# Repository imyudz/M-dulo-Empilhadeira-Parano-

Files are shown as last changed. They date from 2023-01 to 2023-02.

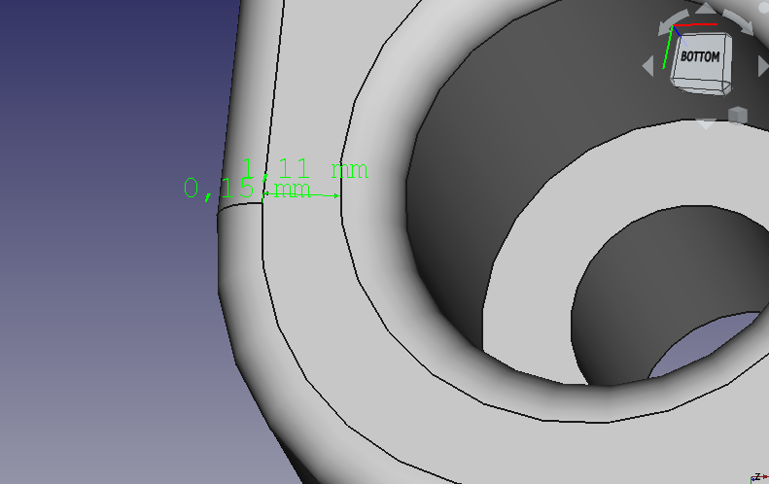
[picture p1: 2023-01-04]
Físico/CASE/VS1/cotas escariado tampa.png

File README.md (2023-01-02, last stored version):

# Módulo Empilhadeira Paranoá -- IIOT, Indústria 4.0

Desenvolvido por mim, para automatizar os chamados de empilhadeira da empresa Paranoa em conjunto com a DataWake
O projeto consiste na utilização de:
- ESP8266 ou ESP32
- Modelagem 3D para comportar a placa utilizada
- Comunicação do ESP com Software Supervisório ELIPSE E3 via MQTT

Todas as etapas desenvolvidas durante o ano de 2022 por mim.

OBJETIVO: A máquina, quando identificada através de sensores que precisa abastecer algum material, já realiza um chamado para o dispositivo que está fixado na empilhadeira

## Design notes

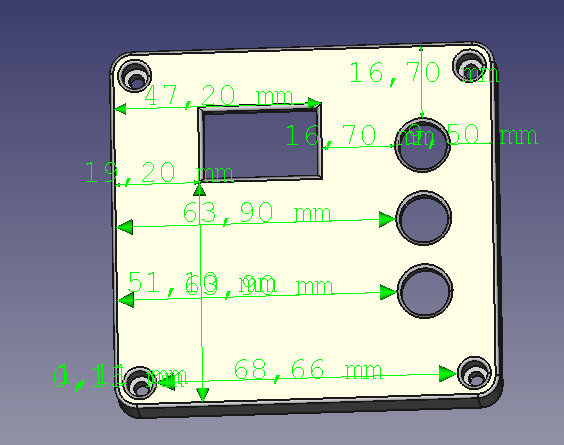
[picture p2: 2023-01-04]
Físico/CASE/VS1/cotas tampa interia.png

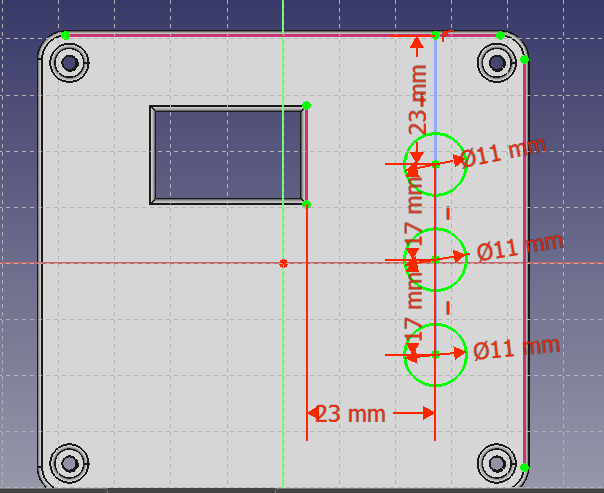
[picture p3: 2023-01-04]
Físico/CASE/VS1/cotas 1 - botões.png

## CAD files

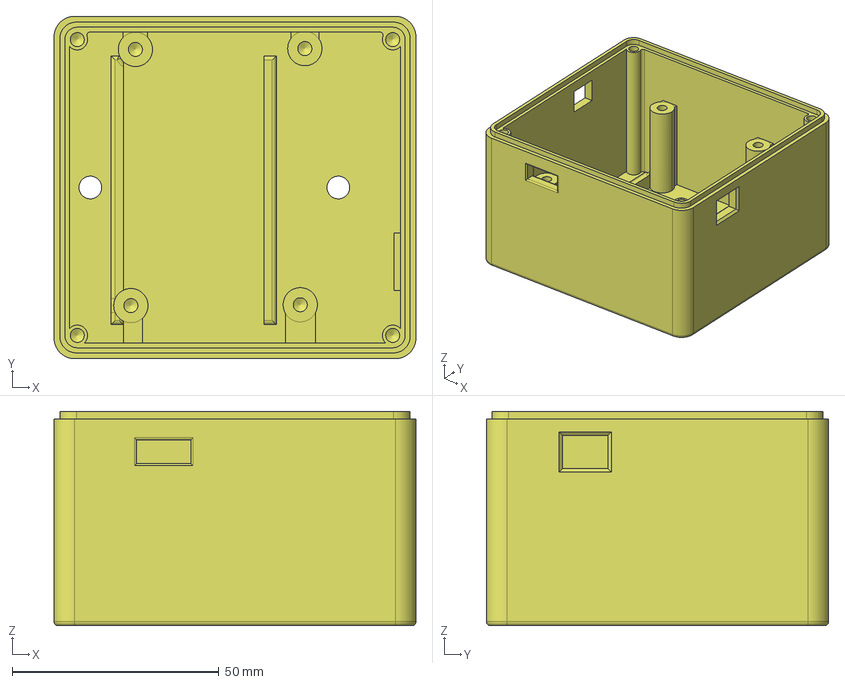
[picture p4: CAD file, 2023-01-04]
Físico/CASE/VS1/CASE DEFINITIVO - BACKUP.FCStd
87.6 x 82.8 x 51.9 mm

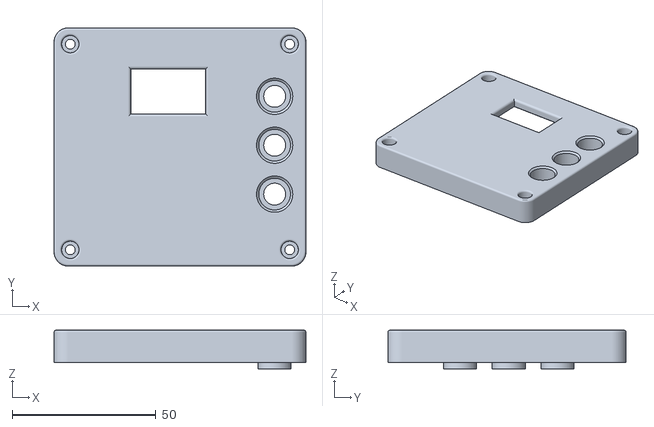
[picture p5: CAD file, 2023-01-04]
Físico/CASE/VS1/IMPRESSÃO vs1/CASE DEFINITIVO-TAMPA.stl
87.6 x 82.8 x 13.5

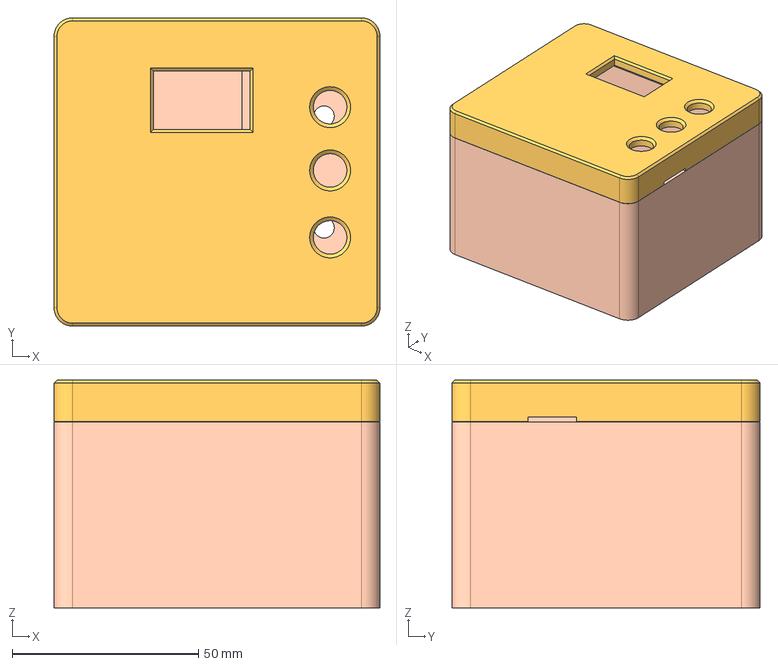
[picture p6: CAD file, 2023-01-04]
Físico/CASE/VS2/CASE DEFINITIVO MUTÁVEL VS 2.FCStd
87.6 x 82.8 x 61.2 mm
CASE_NO_BREAKABLE
TAMPA

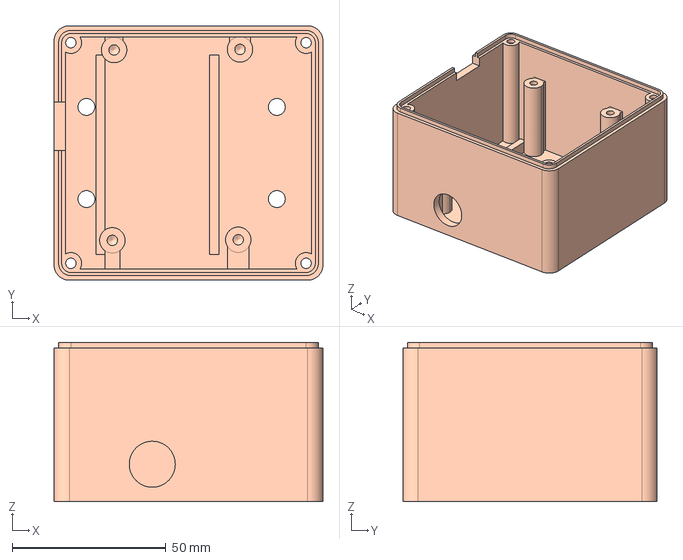
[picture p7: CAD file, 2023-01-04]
Físico/CASE/VS3.1/CASE DEFINITIVO MUTÁVEL VS 3.1.FCStd
87.6 x 82.8 x 51.9 mm

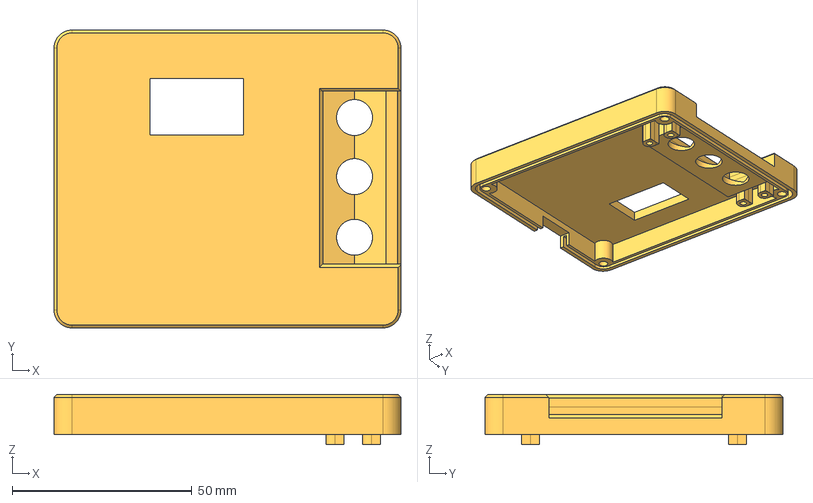
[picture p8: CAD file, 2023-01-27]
Físico/CASE/VS4/CASE DEFINITIVO MUTÁVEL VS 4.FCStd
96.5 x 82.8 x 14.0 mm

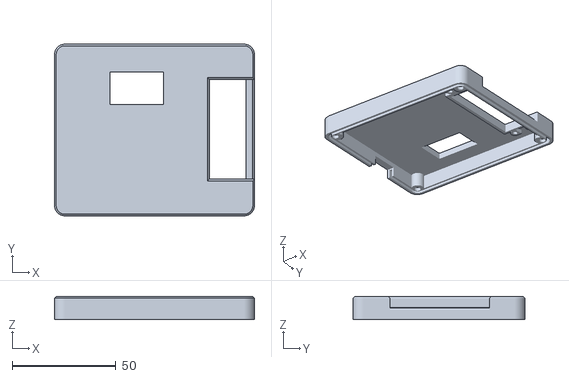
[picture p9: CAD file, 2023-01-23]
Físico/CASE/VS4/Impressão/CASE DEFINITIVO MUTÁVEL VS 4-TAMPA.stl
96.5 x 82.8 x 11.2

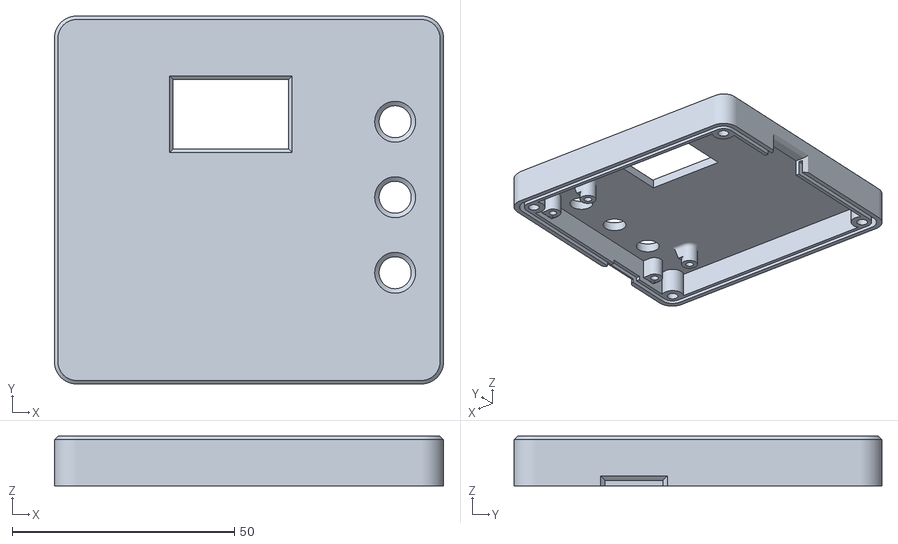
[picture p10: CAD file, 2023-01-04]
Físico/CASE/VS2/IMPRESSÃO vs2/CASE DEFINITIVO MUTÁVEL VS 2-TAMPA.stl
87.6 x 82.8 x 11.2

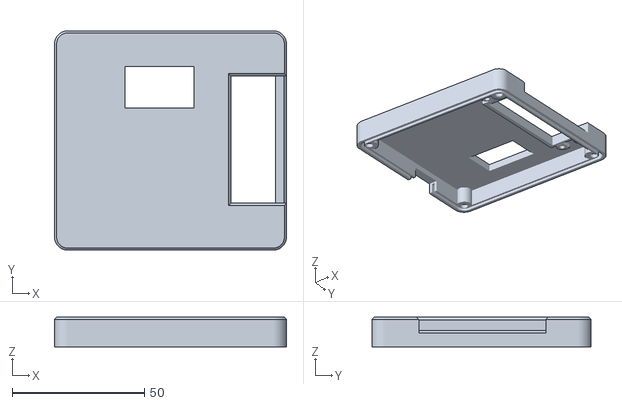
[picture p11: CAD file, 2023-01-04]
Físico/CASE/VS3.1/IMPRESSAO 3.1/TAMPA_3.1.stl
87.6 x 82.8 x 11.2

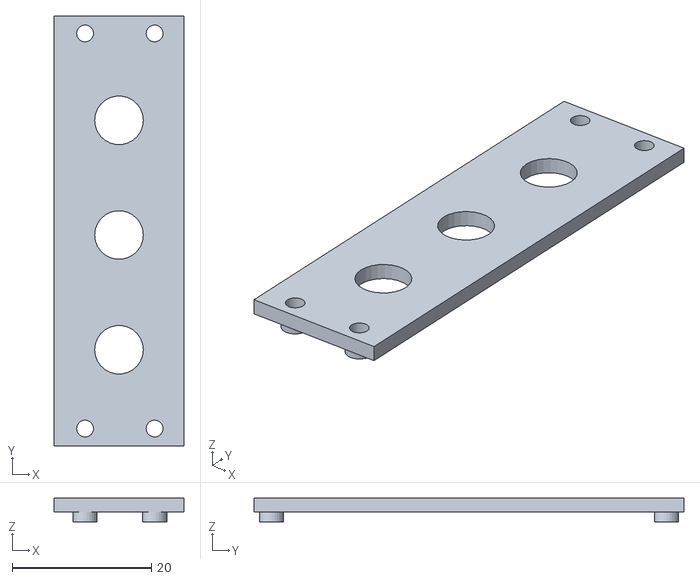
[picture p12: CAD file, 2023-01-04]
Físico/CASE/VS3.1/IMPRESSAO 3.1/BOTOES_3.1.stl
18.7 x 61.8 x 3.40

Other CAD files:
Físico/CASE/VS3.1/IMPRESSAO 3.1/CASE 3.1.stl
Físico/CASE/VS3/CASE DEFINITIVO MUTÁVEL VS 3.FCStd
Físico/CASE/VS1/IMPRESSÃO vs1/CASE DEFINITIVO-CASE.stl
Físico/CASE/VS2/IMPRESSÃO vs2/CASE DEFINITIVO MUTÁVEL VS 2-tampa vs2.stl

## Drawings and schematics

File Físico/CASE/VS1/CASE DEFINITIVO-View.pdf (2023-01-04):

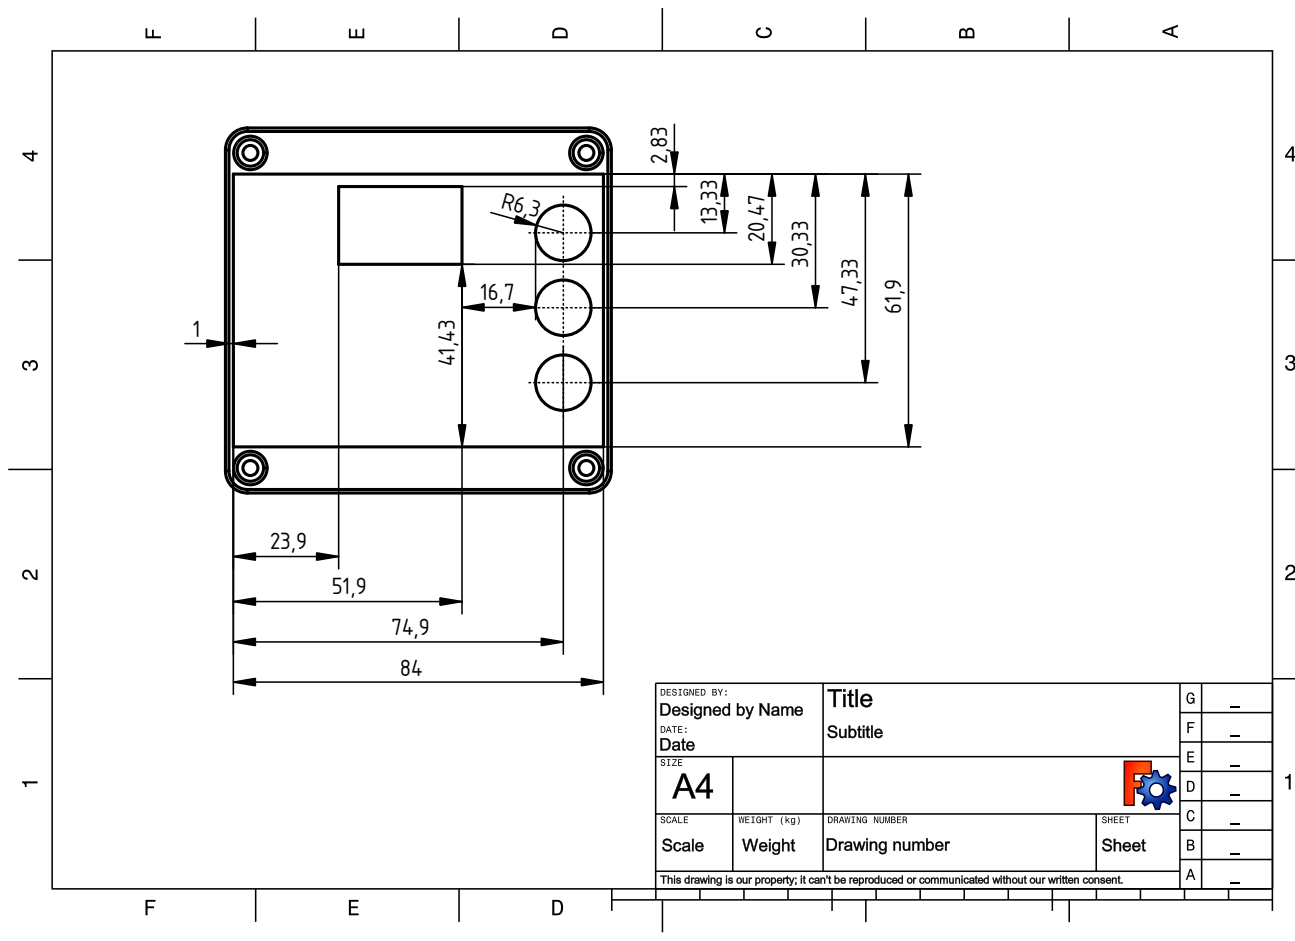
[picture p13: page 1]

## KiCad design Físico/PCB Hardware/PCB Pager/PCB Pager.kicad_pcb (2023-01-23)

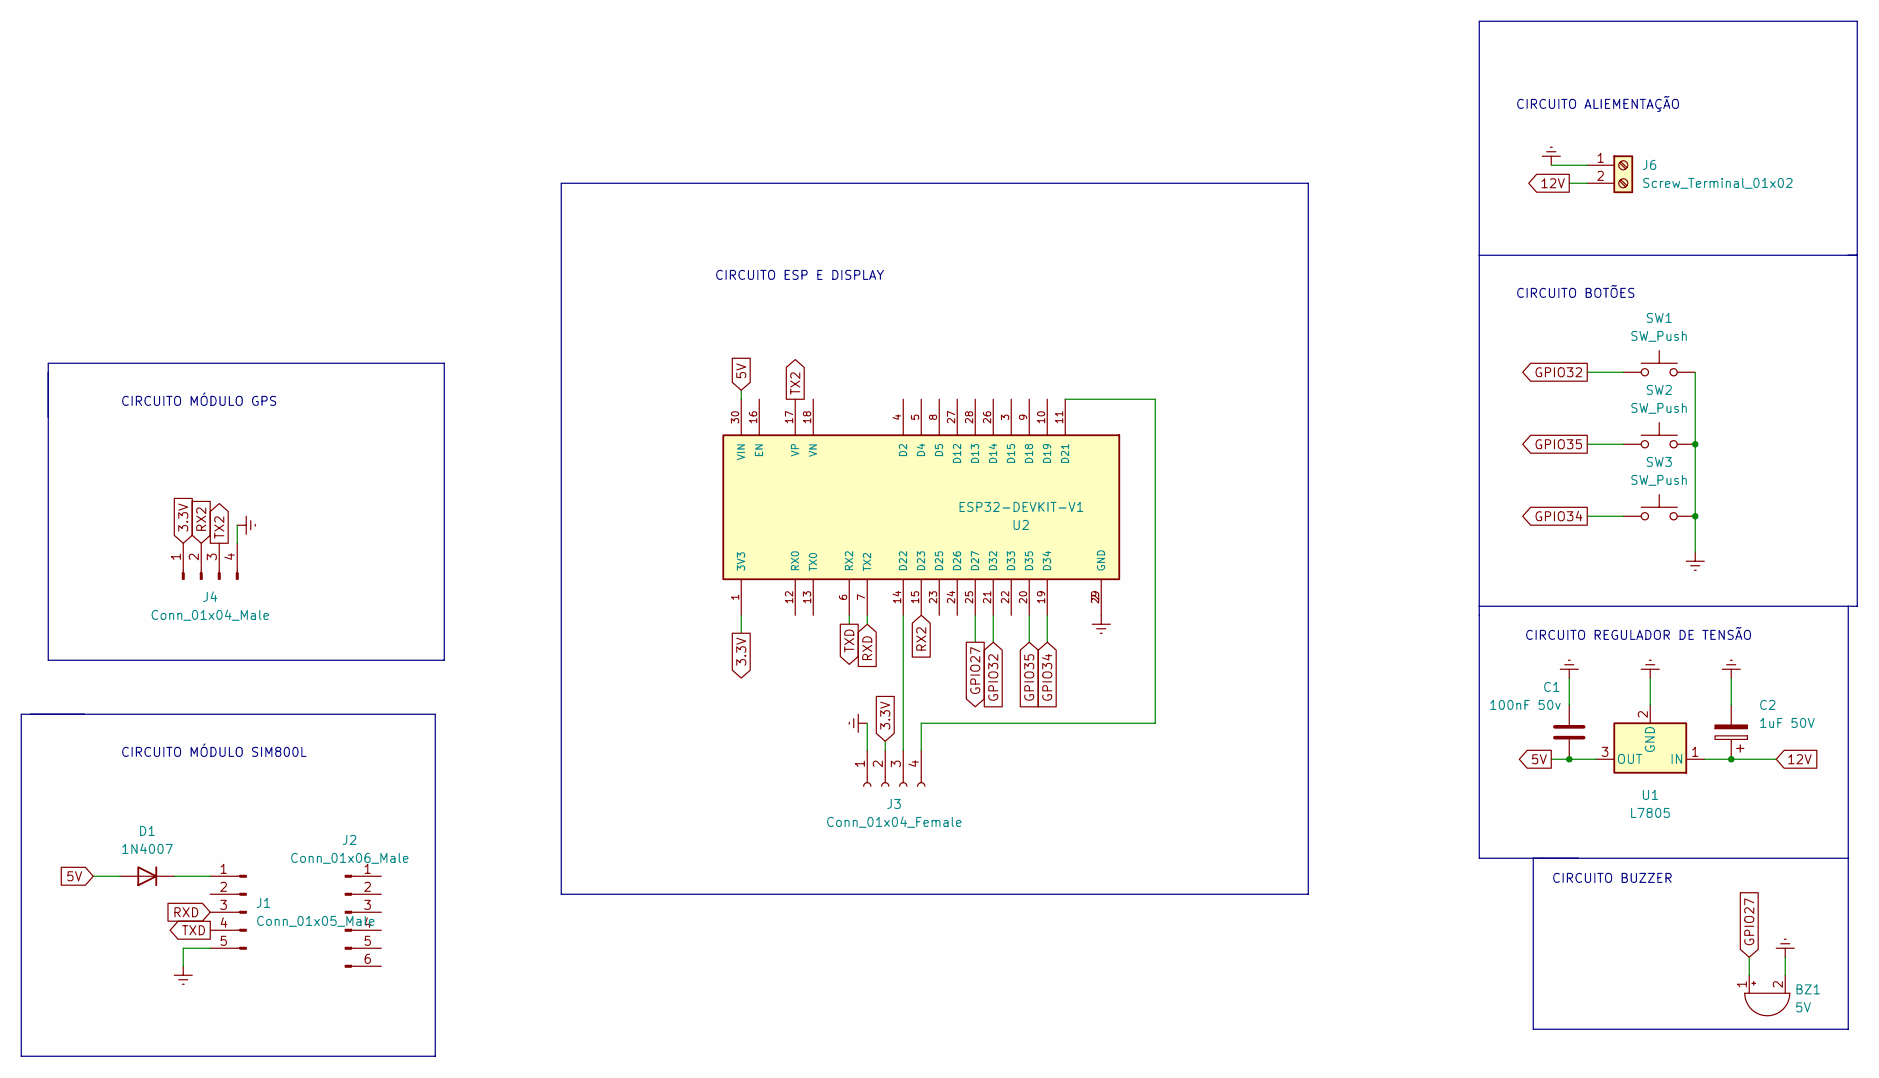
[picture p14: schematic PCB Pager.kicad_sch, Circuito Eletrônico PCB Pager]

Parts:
BZ1: 5V; Buzzer_12x9.5RM7.6
C1: 100nF 50v; C_Disc_D7.5mm_W4.4mm_P5.00mm
C2: 1uF 50V; CP_Radial_D5.0mm_P2.50mm
D1: 1N4007; D_DO-41_SOD81_P10.16mm_Horizontal
J1: Conn_01x05_Male; PinHeader_1x05_P2.54mm_Vertical
J2: Conn_01x06_Male; PinHeader_1x06_P2.54mm_Vertical
J3: Conn_01x04_Female; PinSocket_1x04_P2.54mm_Vertical
J4: Conn_01x04_Male; PinHeader_1x04_P2.54mm_Vertical
J6: Screw_Terminal_01x02; TerminalBlock_bornier-2_P5.08mm
SW1, SW2, SW3: SW_Push; SW_PUSH-12mm
U1: L7805; TO-220-3_Horizontal_TabDown
U2: ESP32-DEVKIT-V1; MODULE_ESP32_DEVKIT_V1; PARTREV N/A

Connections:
3.3V: J3.2, J4.1, U2.1 (3V3)
5V: C1.1, D1.2 (A), U1.3 (OUT), U2.30 (VIN)
12V: C2.1, J6.2, U1.1 (IN)
Earth: BZ1.2 (+), C1.2, C2.2, J1.5, J3.1, J4.4, J6.1, SW1.2, SW2.2, SW3.2, U1.2 (GND), U2.2 (GND), U2.29 (GND)
GPIO27: BZ1.1 (-), U2.25 (D27)
GPIO32: SW1.1, U2.21 (D32)
GPIO34: SW3.1, U2.19 (D34)
GPIO35: SW2.1, U2.20 (D35)
unnamed: D1.1 (K), J1.1
unnamed: J3.3, U2.14 (D22)
unnamed: J3.4, U2.11 (D21)
RX2: J4.2, U2.15 (D23)
RXD: J1.3, U2.7 (TX2)
TX2: J4.3, U2.17 (VP)
TXD: J1.4, U2.6 (RX2)

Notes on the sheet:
CIRCUITO BOTÕES
CIRCUITO BUZZER
CIRCUITO MÓDULO GPS
CIRCUITO ALIEMENTAÇÃO
CIRCUITO ESP E DISPLAY
CIRCUITO REGULADOR DE TENSÃO
CIRCUITO MÓDULO SIM800L

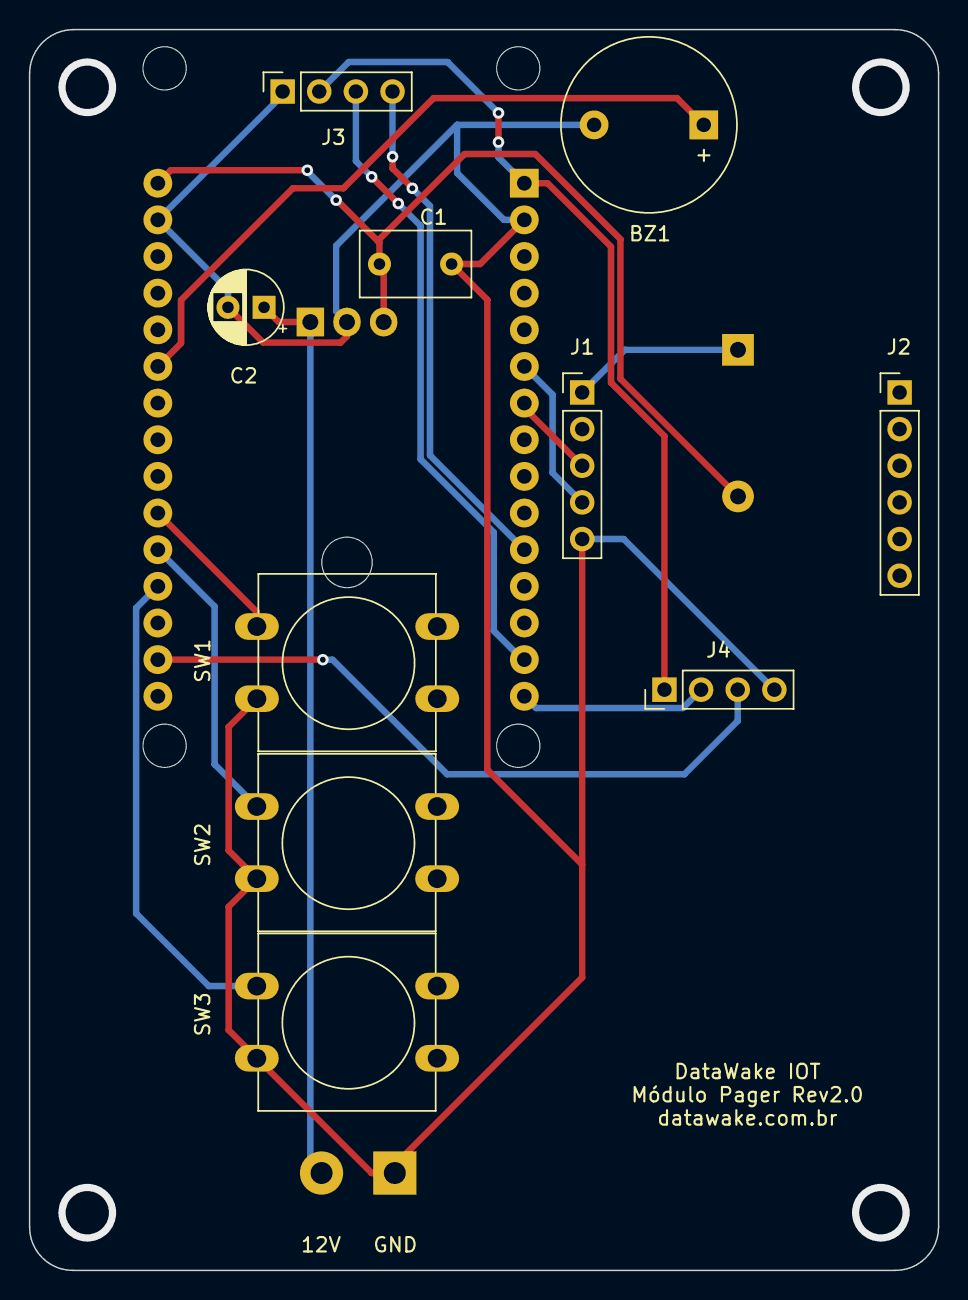
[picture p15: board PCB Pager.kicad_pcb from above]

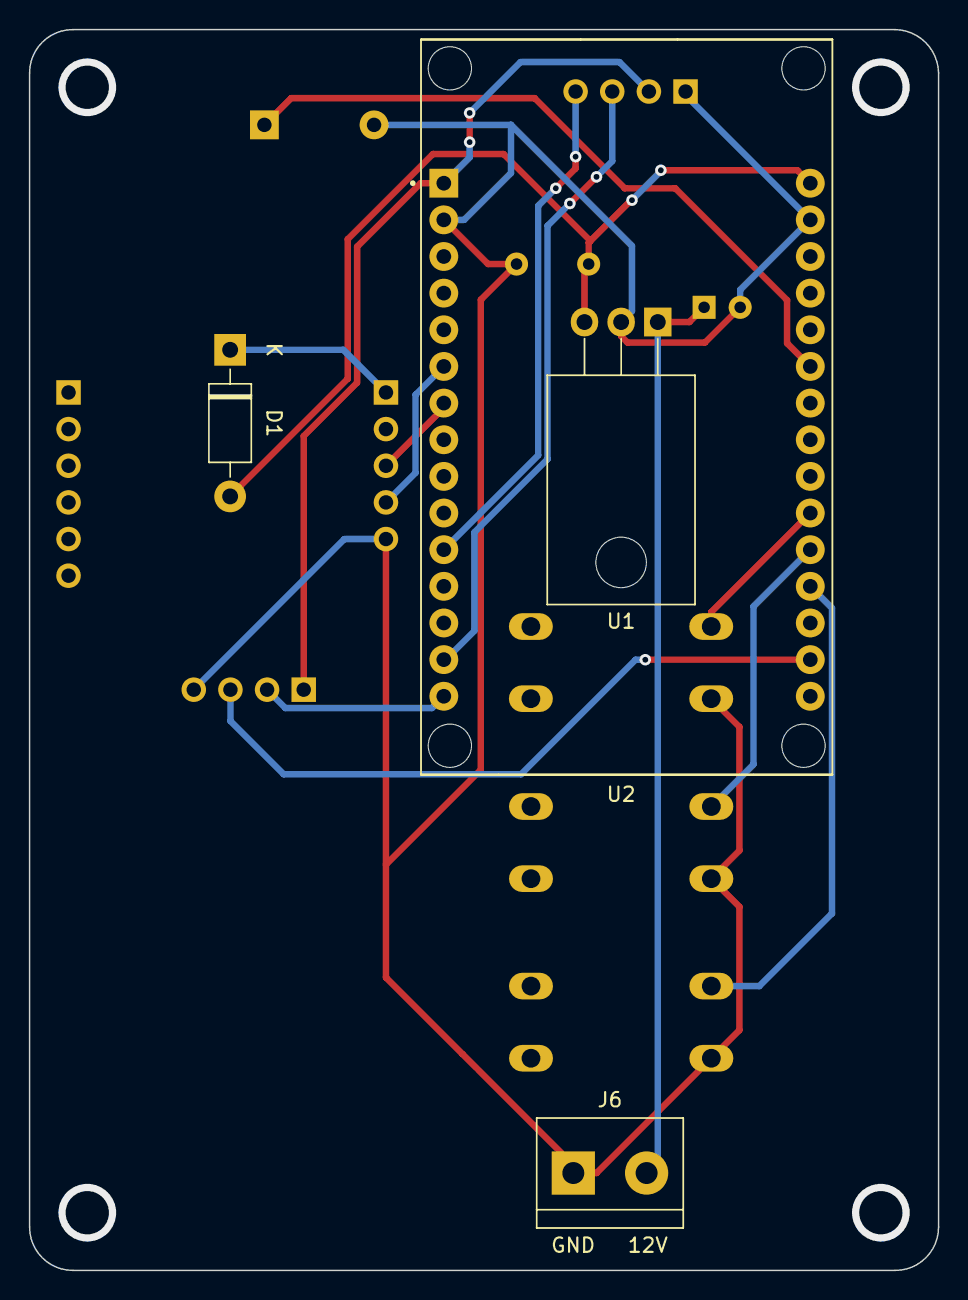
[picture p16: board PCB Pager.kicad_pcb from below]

Board: 2 copper layers, 63.0 x 86.0 mm, 14 parts (4 on the bottom side), 15 nets.

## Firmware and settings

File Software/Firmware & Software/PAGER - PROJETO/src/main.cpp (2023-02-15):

/*
  PREDEFINIÇÕES PARA OS STATUS DO PAGER
    0-LAST WILL
    1-RECEBIDO
    2-ACEITO
    3-CANCELADO
    4-PARADO
    5-FINALIZADO
    6-DESCONECTADO COM OPERAÇÃO EM ANDAMENTO
    7-PARADA FINALIZADA
*/

////////////////////////////////////////////////////////////////////////////////////////////////////////////

/////////////////////////////////////////////////////////////////////////////////////////////////////////////
//                                            BIBLIOTECAS
/////////////////////////////////////////////////////////////////////////////////////////////////////////////
#include        <Arduino.h>          //padrões arduino
#include        <Wire.h>             //Display
#include        "SSD1306.h"          //Display
#include        <PubSubClient.h>     //MQTT
#include        <WiFiClient.h>       //MQTT
#include        <ESP8266WiFi.h>      //WiFi
#include        <Preferences.h>      //EEPROM
#include        <neotimer.h>         //Substituição do Millis

/////////////////////////////////////////////////////////////////////////////////////////////////////////////
//                                            CÓDIGO DE PARADAS                                            //
////////////////////////////////////////////////////////////////////////////////////////////////////////////
String    MANUT_MEC       =    "2";
String    MANUT_EL        =    "1";
String    BANHEIRO        =    "7";
String    REFEICAO        =    "9";
String    AUDITORIA       =    "11";
String    TREINAMENTO     =    "13";
String    TRY_OUT         =    "17";
String    FALTA_ABASTEC   =    "24";
String    MANUT_PREV      =    "25";
String    TESTES_DIV      =    "36";
String    NAO_APONTADO    =    "49";
String    TESTE_MANUT     =    "59";
String    AGUARD_EMPILH   =    "76";

String cod_parada = "";

////////////////////////////////////////////////////////////////////////////////////////////////////////////
//                                      Configuração WIFI
////////////////////////////////////////////////////////////////////////////////////////////////////////////
const char* ssid = "ParanoaSA";
const char* password = "0e6f1e0dff";
//const char* ssid = "victor";
//const char* password = "admin123";
WiFiClient wifiClient;


////////////////////////////////////////////////////////////////////////////////////////////////////////////
//                                      Configuração MQTT
////////////////////////////////////////////////////////////////////////////////////////////////////////////
//*************************SERVER:
//const char* BROKER_MQTT = "192.168.0.82"; // URL OU IP DO BROKER que se deseja utilizar -- SERVIDOR DE FUNCIONAMENTO
const char* BROKER_MQTT = "192.168.0.13"; // URL OU IP DO BROKER que se deseja utilizar -- SERVIDOR DE TESTE
//const char* BROKER_MQTT = "broker.hivemq.com"; // URL OU IP DO BROKER que se deseja utilizar -- SERVIDOR DE TESTE
int BROKER_PORT = 1883; //Porta do BROKER MQTT
#define MQTTsubQos  1   //qos of subscribe
#define MQTTpubQos  1   //qos of subscribe
//*************************CLIENT:
PubSubClient MQTT(wifiClient); //Instancia objeto MQTT que se vincula ao objeto do espClient
//****************DEFINE OS TÓPICOS DESSE PAGER
#define TOPIC_PUBLISH "PG2/STATUS"
const char* PAGER_NAME = "PG2";
String STATUS_PAGER = (String)PAGER_NAME+"/STATUS";
String UNIDADE = (String)PAGER_NAME+"/LOCAL";
String PRODUTO = (String)PAGER_NAME+"/PRODUTO";
String SOLICITACAO = (String)PAGER_NAME+"/SOLICITACAO";
String COD_PARADA = (String)PAGER_NAME+"/CODPARADA";
String ETIQ_MONTARACK = (String)PAGER_NAME+"/ETIQ_MONTARACK";


///////////////////////////////////////////////////////////////////////////////////////////////////////////
//                                     MAPEAMENTO DE HARDWARE
//////////////////////////////////////////////////////////////////////////////////////////////////////////
//definições para os botões da placa
unsigned long tempo_botao = millis();
#define btcima 2 //D4
#define btbaixo 12 //D3
#define btenter 0 //D6
#define buzzer 14
#define DEBOUNCE_BOTAO 300
#define QUANT_VEZES_BUZZER 4


///////////////////////////////////////////////////////////////////////////////////////////////////////////////
//                                   CONFIGURAÇÕES DO MENU E DISPLAY
///////////////////////////////////////////////////////////////////////////////////////////////////////////////
//Adafruit_SSD1306 display(128, 64, &Wire, -1);
SSD1306Wire display(0x3c, SDA, SCL);
//variaveis menu
byte navegacao_status = 0; //controla em qual página do MENU o dispositivo se encontra durante a navegação
byte altera_parametros = 0; //indica o parâmtro que está sendo atualizado
String sts_sistema = "";   //define o status da integridade dos dados do dispositivo. Se o valor for maior que 0, alguma informação não foi cadastrada no dispositivo e por isso não acontecerá a comunicação com o servidor MQTT
String produtoDisplay; //recebe o produto que foi atribuido


////////////////////////////////////////////////////////////////////////////////////////////////////////
//                                       Configurações EEPROM                                         //
////////////////////////////////////////////////////////////////////////////////////////////////////////
#define EEPROM_SOLICITACOES "blocoSolicitacoes"
#define EEPROM_ETIQUETA "blocoEtiqueta"
#define EEPROM_ENDERECO_SOLICITACOES "id_solicitacoes"
#define EEPROM_ENDERECO_ETIQUETA "cod_etiquetaMontaRack"
Preferences EEPROMdata;
float id_solicitacoes;

////////////////////////////////////////////////////////////////////////////////////////////////////////
//                                       Configurações NEOTIMER                                       //
///////////////////////////////////////////////////////////////////////////////////////////////////////
Neotimer tempoBuzzerLigado = Neotimer(70);
Neotimer tempoBuzzerDesligado = Neotimer(70);


///////////////////////////////////////////////////////////////////////////////////////////////////////////////
//                                           TAGS GLOBAIS                                                    //
///////////////////////////////////////////////////////////////////////////////////////////////////////////////
String status_chamada = "";
String produto = "";
String local = "";
String solicitacao = "";
String etiq_montaRack = "";
int selecionado = 0;
int navegado = -1;
int selecionadoOP = 0;
int navegadoOP = -1;
int selecionadoParada = 0;
int navegadoParada = -1;
int selecionadoFinalParada = 0;
int navegadoFinalParada = -1;
unsigned long ultimoEnvio = 0;
unsigned long ultimoEnvio1 = millis();
unsigned long ultimoEnvio2 = 0;
unsigned long ultimoEnvio3 = 0;
unsigned long ultimoEnvio4 = 0;
unsigned long ultimoEnvio5 = millis();
unsigned long ultimoEnvio6 = 0;
unsigned long ultimoEnvio7 = 0;
unsigned long ultimaChamada = 0;
unsigned long esperaRetornoReinicio = millis();
int salva_ponto;
int estado_antes_parada = 0;
int flag = 0;
boolean desconexaoPendente = false;


//////////////////////////////////////////////////////////////////////////////////////////////////////////////
//Endereços de Imagens 
/////////////////////////////////////////////////////////////////////////////////////////////////////////////
const unsigned char PROGMEM logo_dw [] = {0x00, 0x00, 0x00, 0x00, 0x00, 0x00, 0x00, 0x00, 0x00, 0x00, 0x00, 0x00, 0x00, 0x00, 0x00, 0x00, 0x00, 0x00, 0x00, 0x00, 0x00, 0x00, 0x00, 0x00, 0x00, 0x00, 0x00, 0x00, 0x00, 0x00, 0x01, 0xC0, 0x00, 0x00, 0x00, 0x00, 0x01, 0xC0, 0x00, 0x00, 0x00, 0x00, 0x00, 0x0F, 0x80, 0x03, 0x80, 0x00, 0x00, 0x0F, 0xF0, 0x03, 0x80, 0x00, 0x00, 0x0F, 0xF8, 0x07, 0xC0, 0x00, 0x00, 0x70, 0x3C, 0x07, 0xC0, 0x00, 0x00, 0x70, 0x1E, 0x06, 0xE0, 0x00, 0x00, 0x70, 0x0E, 0x0E, 0xE0, 0x00, 0x00, 0x70, 0x07, 0x0C, 0x70, 0x00, 0x00, 0x70, 0x07, 0x1C, 0x70, 0x00, 0x00, 0x70, 0x07, 0x1C, 0x38, 0x00, 0x00, 0x70, 0x07, 0x38, 0x38, 0x00, 0x00, 0x70, 0x07, 0x38, 0x38, 0x00, 0x00, 0x70, 0x0E, 0x70, 0x1C, 0x00, 0x00, 0x70, 0x1E, 0x70, 0x1C, 0x00, 0x00, 0x70, 0x7C, 0x60, 0x0E, 0x00, 0x00, 0x7F, 0xF8, 0xE0, 0x0E, 0x00, 0x00, 0x7F, 0xF0, 0xE0, 0x07, 0x00, 0x00, 0x00, 0x00, 0x00, 0x00, 0x00, 0x00, 0x00, 0x00, 0x00, 0x00, 0x00, 0x00, 0x00, 0x00, 0x00, 0x00, 0x00, 0x00, 0x30, 0x01, 0xC0, 0x07, 0x00, 0x00, 0x38, 0x01, 0xE0, 0x0E, 0x00, 0x00, 0x18, 0x03, 0xE0, 0x0E, 0x00, 0x00, 0x1C, 0x03, 0xF0, 0x0C, 0x00, 0x00, 0x1C, 0x07, 0x70, 0x1C, 0x00, 0x00, 0x0E, 0x07, 0x30, 0x18, 0x00, 0x00, 0x0E, 0x0E, 0x38, 0x38, 0x00, 0x00, 0x06, 0x0E, 0x38, 0x38, 0x00, 0x00, 0x07, 0x0C, 0x1C, 0x70, 0x00, 0x00, 0x03, 0x1C, 0x1C, 0x70, 0x00, 0x00, 0x03, 0x9C, 0x0E, 0x60, 0x00, 0x00, 0x03, 0xB8, 0x0E, 0xE0, 0x00, 0x00, 0x01, 0xF8, 0x06, 0xC0, 0x00, 0x00, 0x01, 0xF0, 0x07, 0xC0, 0x00, 0x00, 0x00, 0xF0, 0x07, 0xC0, 0x00, 0x00, 0x00, 0xE0, 0x03, 0x80, 0x00, 0x00, 0x00, 0x00, 0x00, 0x00, 0x00, 0x00, 0x00, 0x00, 0x00, 0x00, 0x00, 0x00, 0x00, 0x00, 0x00, 0x00, 0x00, 0x00, 0x00, 0x00, 0x00, 0x00, 0x00, 0x00, 0x00, 0x00, 0x00, 0x00, 0x00, 0x00, 0x00, 0x00, 0x00, 0x00, 0x00};
/*const unsigned char PROGMEM icone_config [] = {0x00, 0x00, 0x04, 0x20, 0x00, 0x00, 0x0E, 0x70, 0x00, 0x00, 0x0F, 0xF0, 0x00, 0x00, 0x0F, 0xF0, 0x00, 0x00, 0x7F, 0xFE, 0x00, 0x00, 0xFE, 0x7F, 0x00, 0x00, 0x7C, 0x3E, 0x00, 0x00, 0x38, 0x1C, 0x00, 0x00, 0x38, 0x1C, 0x00, 0x00, 0x7C, 0x3E, 0x00, 0x00, 0xFE, 0x7F, 0x00, 0x70, 0x7F, 0xFE, 0x00, 0x70, 0x0F, 0xF0, 0x00, 0x70, 0x0F, 0xF0, 0x1C, 0xF9, 0xCE, 0x70, 0x3F, 0xFF, 0xE4, 0x20, 0x1F, 0xFF, 0xC0, 0x00, 0x0F, 0xFF, 0x80, 0x00, 0x1F, 0x8F, 0x80, 0x00, 0x1F, 0x07, 0xC0, 0x00, 0xFE, 0x03, 0xF8, 0x00, 0xFE, 0x03, 0xF8, 0x00, 0xFE, 0x03, 0xF8, 0x00, 0x1E, 0x07, 0xC0, 0x00, 0x1F, 0x07, 0x80, 0x00, 0x0F, 0xFF, 0x80, 0x00, 0x1F, 0xFF, 0xC0, 0x00, 0x3F, 0xFF, 0xC0, 0x00, 0x1D, 0xFD, 0xC0, 0x00, 0x08, 0x70, 0x80, 0x00, 0x00, 0x70, 0x00, 0x00, 0x00, 0x70, 0x00, 0x00};*/
/*const unsigned char PROGMEM icone_info [] = {0x7F, 0xFF, 0xFF, 0xF0, 0xC0, 0x00, 0x00, 0x10, 0x80, 0x00, 0x00, 0x10, 0x80, 0x00, 0x00, 0x10, 0xFF, 0xFF, 0xFF, 0xF0, 0xFF, 0xFF, 0xFF, 0xF0, 0x80, 0x00, 0x00, 0x10, 0x80, 0x00, 0x00, 0x10, 0x80, 0x00, 0x00, 0x10, 0x80, 0x00, 0x00, 0x10, 0x8E, 0x7F, 0xFF, 0x10, 0x80, 0x00, 0x00, 0x10, 0x80, 0x00, 0x00, 0x10, 0x8E, 0x7F, 0xFF, 0x10, 0x80, 0x00, 0x00, 0x10, 0x80, 0x00, 0x00, 0x10, 0x8E, 0x7F, 0xFF, 0x10, 0x80, 0x00, 0x00, 0x10, 0x80, 0x00, 0x00, 0x10, 0x86, 0x7F, 0xC0, 0x10, 0x80, 0x00, 0x03, 0x00, 0x80, 0x00, 0x1F, 0xE0, 0x80, 0x00, 0x33, 0x38, 0x80, 0x00, 0xCF, 0xCC, 0x80, 0x01, 0x88, 0x46, 0xFF, 0xFB, 0x1B, 0x63, 0x00, 0x03, 0x1B, 0x23, 0x00, 0x01, 0x98, 0x66, 0x00, 0x00, 0xCC, 0xCC, 0x00, 0x00, 0x67, 0x98, 0x00, 0x00, 0x3C, 0xF0, 0x00, 0x00, 0x0F, 0xC0};*/


//////////////////////////////////////////////////////////////////////////////////////////////////////////////
//                                         Códigos das Funções                                              //
/////////////////////////////////////////////////////////////////////////////////////////////////////////////
void (*funcReset)() = 0;

void apitaBuzzer(){
  for (int i = 0; i < QUANT_VEZES_BUZZER; i++)
  {
    //LÓGICA EM TESTE:
    /*  tempoBuzzerLigado.start();
      if(tempoBuzzerLigado.waiting()) digitalWrite(buzzer, HIGH);
      if(tempoBuzzerLigado.done()){ digitalWrite(buzzer, LOW); tempoBuzzerDesligado.start();}
      if(tempoBuzzerDesligado.waiting()) digitalWrite(buzzer, LOW);
      if(tempoBuzzerDesligado.done()) tempoBuzzerLigado.reset();
      tempoBuzzerDesligado.reset();
    */
    digitalWrite(buzzer, HIGH);
    delay(60);
    digitalWrite(buzzer, LOW);
    delay(60);
  }
}


void menu_seleciona(){//MENU PARA SELECIONAR A AÇÃO QUANDO APARECE UMA CHAMADA
  int y_pos = 22;
  const char *opcoes[3] = {
    " ACEITAR",
    " VOLTAR",
    " PARADA"
  };

  if (navegado == -1) {
    display.clear();
    display.setTextAlignment(TEXT_ALIGN_LEFT);
    display.setFont(ArialMT_Plain_10);
    display.setColor(WHITE);
    display.drawString(0, 0,"ESCOLHA UMA OPÇÃO");
    for (int i = 0; i < 3; i++) {
      if (i == selecionado) {
        display.setTextAlignment(TEXT_ALIGN_LEFT);
        display.setFont(ArialMT_Plain_16);
        //Serial.println(opcoes[i]);
        if (y_pos < 50){
          display.drawString(20, y_pos, ">");
          display.drawString(27, y_pos, opcoes[i]);
          y_pos += 15;
        }
        else
        {
          display.setColor(BLACK);
          y_pos = 22;
          display.fillRect(20, y_pos, 160, 50);
          display.setColor(WHITE);
          display.drawString(20, y_pos, ">");
          display.drawString(27, y_pos, opcoes[i]);
        }
      } else if (i != selecionado) {
        display.setTextAlignment(TEXT_ALIGN_LEFT);
        display.setFont(ArialMT_Plain_16);
        display.setColor(WHITE);
        if (y_pos < 50){
          display.drawString(22, y_pos, opcoes[i]);
          y_pos+= 15;
        }
        else
        {
          display.setBrightness(255);
          display.setContrast(255);
          display.setFont(ArialMT_Plain_10);
          display.drawString(30, y_pos, opcoes[i]);
        }
      }
    }
  }
  display.display();
}

void menu_selecionaEmOperacao(){ //MENU PARA SELECIONAR A AÇÃO ENQUANTO ESTIVER EM OPERAÇÃO (STATUS = 2)
  
  int y_pos = 20;
  const char *opcoes[4] = {
    " FINALIZAR",
    " VOLTAR",
    " CANCELAR",
    " PARADA"
  };
  if (navegadoOP == -1) {
    display.clear();
    display.setTextAlignment(TEXT_ALIGN_LEFT);
    display.setFont(ArialMT_Plain_10);
    display.setColor(WHITE);
    display.drawString(0, 0,"ESCOLHA UMA OPÇÃO");
    for (int i = 0; i < 4; i++) {
      if (i == selecionadoOP) {
        display.setTextAlignment(TEXT_ALIGN_LEFT);
        display.setFont(ArialMT_Plain_16);
        if (y_pos < 50){
          display.drawString(20, y_pos, ">");
          display.drawString(27, y_pos, opcoes[i]);
          y_pos += 15;
        }
        else
        {
          display.setColor(BLACK);
          y_pos = 16;
          display.fillRect(20, y_pos, 160, 50);
          display.setColor(WHITE);
          display.drawString(20, y_pos, ">");
          display.drawString(27, y_pos, opcoes[i]);
          y_pos+= 15;
        }
      } else if (i != selecionadoOP) {
        display.setTextAlignment(TEXT_ALIGN_LEFT);
        display.setFont(ArialMT_Plain_16);
        display.setColor(WHITE);
        if (y_pos < 50){
          display.drawString(22, y_pos, opcoes[i]);
          y_pos+= 15;
        }
        else
        {
          display.setBrightness(255);
          display.setContrast(255);
          display.setFont(ArialMT_Plain_10);
          display.drawString(30, y_pos, opcoes[i]);
          y_pos += 15;
        }
      }
    }
  }
  display.display();
}

void menu_motivoParada(){ //MENU PARA SELECIONAR A AÇÃO ENQUANTO ESTIVER EM OPERAÇÃO (STATUS = 2)
  
  int y_pos = 20;
  const char *opcoes[14] = {
    "VOLTAR",   
    "MANUT EL",     
    "BANHEIRO",     
    "REFEICAO",     
    "AUDITORIA",    
    "TREINAMENTO",  
    "TRY OUT",      
    "FALTA ABASTEC",
    "MANUT PREV",   
    "TESTES DIV",   
    "OUTRO", 
    "TESTE MANUT",  
    "AGUARD EMPILH",
  };
  if (navegadoParada == -1) {
    display.clear();
    display.setTextAlignment(TEXT_ALIGN_LEFT);
    display.setFont(ArialMT_Plain_10);
    display.setColor(WHITE);
    display.drawString(0, 0,"ESCOLHA UMA OPÇÃO");
    for (int i = 0; i < 14; i++) {
      if (i == selecionadoParada) {
        display.setTextAlignment(TEXT_ALIGN_LEFT);
        display.setFont(ArialMT_Plain_16);
        if (y_pos < 50){
          display.drawString(10, y_pos, ">");
          display.drawString(17, y_pos, opcoes[i]);
          y_pos += 15;
        }
        else
        {
          display.setColor(BLACK);
          y_pos = 16;
          display.fillRect(0, y_pos, 160, 50);
          display.setColor(WHITE);
          display.drawString(1, y_pos, ">");
          display.drawString(8, y_pos, opcoes[i]);
          y_pos+= 15;
        }
      } else if (i != selecionadoParada) {
        display.setTextAlignment(TEXT_ALIGN_LEFT);
        display.setFont(ArialMT_Plain_16);
        display.setColor(WHITE);
        if (y_pos < 50){
          display.drawString(7, y_pos, opcoes[i]);
          y_pos+= 15;
        }
        else
        {
          display.setBrightness(255);
          display.setContrast(255);
          display.setFont(ArialMT_Plain_10);
          display.drawString(20 , y_pos, opcoes[i]);
          y_pos += 15;
        }
      }
    }
  }
  display.display();
}

void menu_confirmaFinalParada(){//MENU PARA CONFIRMR SE QUER OU NÃO O FINAL DA PARADA
  int y_pos = 22;
  const char *opcoes[2] = {
    " SIM",
    " NÃO"
  };

  if (navegadoFinalParada == -1) {
    display.clear();
    display.setTextAlignment(TEXT_ALIGN_LEFT);
    display.setFont(ArialMT_Plain_10);
    display.setColor(WHITE);
    display.drawString(0, 0,"FINALIZAR PARADA?");
    for (int i = 0; i < 2; i++) {
      if (i == selecionadoFinalParada) {
        display.setTextAlignment(TEXT_ALIGN_LEFT);
        display.setFont(ArialMT_Plain_16);
        display.drawString(20, y_pos, ">");
        display.drawString(27, y_pos, opcoes[i]);
        y_pos += 20;
        Serial.println(opcoes[i]);

      } else if (i != selecionadoFinalParada) {
        display.setTextAlignment(TEXT_ALIGN_LEFT);
        display.setFont(ArialMT_Plain_16);
        display.setColor(WHITE);
        display.drawString(22, y_pos, opcoes[i]);
        y_pos+= 20;
      }
    }
  }
  display.display();
}
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
void loop() {
  //MQTT e WiFi
  processaDesconexoes();

  //Controle de Botões Para Menu
  controle_navegacao(btcima, btenter, btbaixo);
  //**DEBUG**//
  //Serial.print("|||||||||");
  //Serial.println("Navegação Status: "+navegacao_status);
  //Serial.println("Local: "+local);
  //Serial.println("Produto: "+produto);
  //Serial.println("Status chamada: "+status_chamada);
  //Serial.println("Navegado MENU OP: "+navegadoOP);
  //Serial.print(digitalRead(btcima));
  //Serial.print(digitalRead(btbaixo));
  //Serial.println(digitalRead(btenter));
  //Serial.println(selecionadoFinalParada);

  //Controle de Aparições no Display
  controle_display(sts_sistema, MQTT.state());
}

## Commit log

2023-01-04 Novo Commit
    [BOTOES_3.1.stl, CASE 3.1.stl, CASE DEFINITIVO - BACKUP.FCStd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]
2023-01-10 Primeira Versao PCB
    [BOTOES_3.1.stl, CASE 3.1.stl, CASE DEFINITIVO - BACKUP.FCStd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]
2023-01-23 Atualização Parada e Placa Prontas
    [CASE DEFINITIVO MUTÁVEL VS 4-CASE_NO_BREAKABLE.stl, CASE DEFINITIVO MUTÁVEL VS 4-ENCAIXE_BOTOES.stl, CASE DEFINITIVO MUTÁVEL VS 4-TAMPA.stl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]
2023-01-27 BUZZER BIPANDO E CASE NAS MEDIDAS CORRETAS
    [CASE DEFINITIVO MUTÁVEL VS 4.FCStd]
2023-02-15 ATUALIZADO, MOSTRANDO CÓDIGOS DE CHAMADA DAS EMBALAGENS
    [CASE DEFINITIVO MUTÁVEL VS 4-ENCAIXE_BOTOES.stl, V4.1 - CASE DEFINITIVO MUTÁVEL-TAMPA.stl]
